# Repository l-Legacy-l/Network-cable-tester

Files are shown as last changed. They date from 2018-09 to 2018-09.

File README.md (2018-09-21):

# Network-cable-tester
This project was carried out in the first year of a bachelor's degree in computer science at the Haute école en Hainaut.

The purpose of the project is to check the operating status of a network cable (RJ45).
The cable tester includes the LED module and the PIC module. 
2 versions of the PCB have been made, the first one allows to be engraved only in single layer and the second one in double layer (space saving) .

In terms of PIC programming (PIC16F628A), 3 modes have been implemented: 
1. a short press of the button switches to the next LED
2. a long press speeds up the process by automatically switching to the following LED
3. a longer press lights up all the LEDs at the same time

# Usage

You can test the project with the Proteus simulation software and the right cabling.

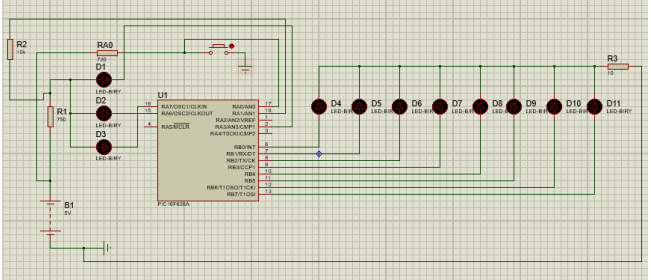
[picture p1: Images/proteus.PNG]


You can also try it in real with a breadboard, the right hardware and MPlab software to upload the code into the PIC.
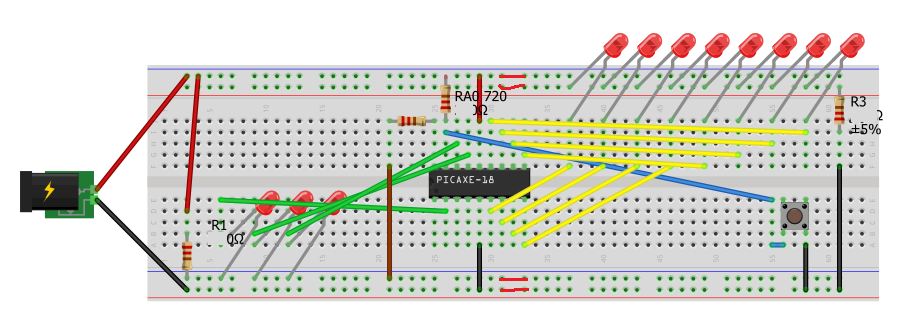
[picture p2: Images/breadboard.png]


You must use the compiled file NetworkCableTester.hex

For more information, you can consult the report detailing the software and hardware used and more detailed explanations (in French).

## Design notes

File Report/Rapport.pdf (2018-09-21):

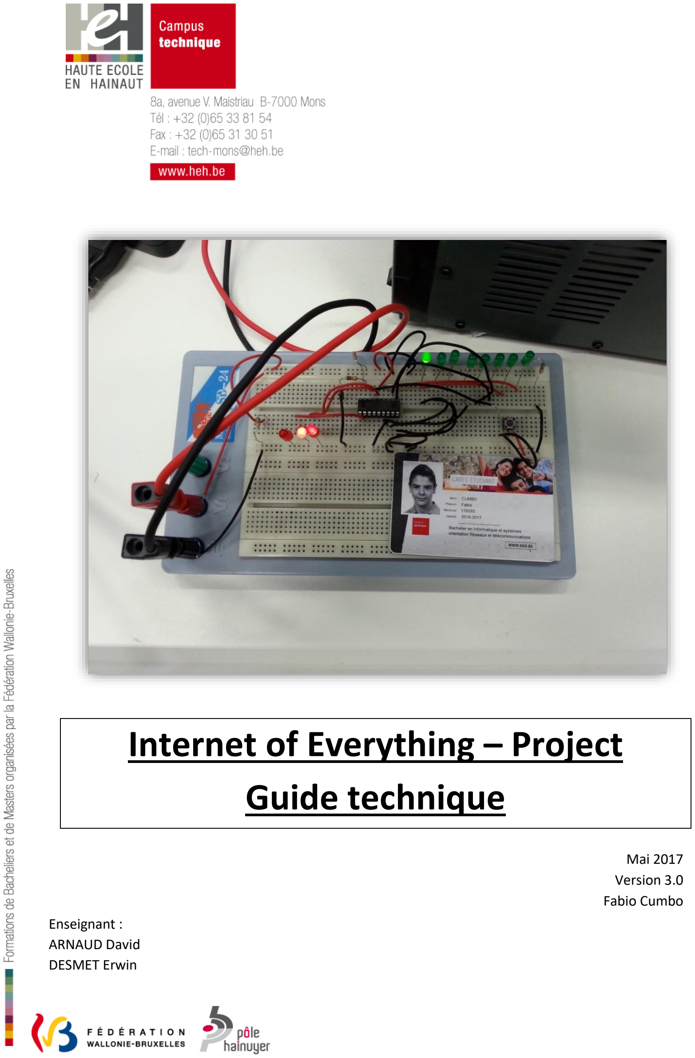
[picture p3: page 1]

# Internet of Everything – Project Guide technique

Mai 2017
Version 3.0
Fabio Cumbo
Enseignant :
ARNAUD David (https://ecampus.heh.be/user/view.php?id=1201&course=1)
DESMET Erwin (https://ecampus.heh.be/user/view.php?id=581&course=1)

Document confidentiel - Usage interne uniquement.

## 1. Informations générales sur le document

### Contact

Pour toute question ou remarque concernant ce document, merci de contacter :

Fabio Cumbo - Etudiant
Mail : fabio.cumbo@std.heh.be
HEH Campus Technique
8A Avenue Maistriau,
7000 Mons

### Confidentialité

Ce document contient des informations confidentielles et exclusives de la Haute École en Hainaut (HEH). Le service informatique ne peut divulguer les informations confidentielles contenues dans ce document à un tiers sans le consentement écrit de la HEH, hormis aux employés, enseignants ou directeurs qui ont besoin de connaître son contenu à des fins d'évaluation du document. Le service informatique se doit d'informer ces personnes de la nature confidentielle de ce document et d'obtenir leur accord pour préserver sa confidentialité.

### Informations sur le document

Nom du document | IoE project Technique.Docx
Version | Version 3.00
Niveau de confidentialité | Utilisation interne uniquement
Auteur du document | Fabio Cumbo

Contributeur(s)

Révisé par

Approuvé par

### Versions

Version | Date de parution | Modification réalisée par | Modification(s) apportée(s)
1.00 | 25/04/2017 | Fabio Cumbo | Création du document
2.00 | 29/05/2017 | Fabio Cumbo | Modification du code pour régler un problème lorsqu’on relâchait le bouton à la dernière LED dans le mode automatique.
3.00 | 30/05/2017 | Fabio Cumbo | Amélioration de l’optimisation du code.

### Documents connexes et/ou de référence

Nom du document | Description | Date
Q1 ETUDE DE PROJET 2016_Testeur_de_cables_reseauV1 | Document du cours d’étude de projet du premier quadrimestre | 16 sept 2016
Q2 EDPsuite 2016, Projet dinterfacage informatique.pdf | Document du cours de projet d’interfaçage informatique du deuxième quadrimestre | 6 fevrier 2017

### Table des matières

Document confidentiel

- Usage interne uniquement.

## 2. Introduction

L’objectif de cette fiche technique est de documenter la réalisation d’un testeur de câble réseau (RJ45) dans le cadre du cours d’étude de projet et du cours de projet d’interfaçage.
Les outils et explications nécessaire à la conception de ce projet seront donc élaboré dans ce document.

## 3. Logiciels et matériels nécessaire à la réalisation du projet

Matériels :
✓ | La liste des composants électronique (5.1.)
✓ | Une breadboard : Simulation réelle
✓ | Une pile 9V pour la breadboard
✓ | Le Pickit 3 pour injecter le code dans le PIC

Logiciels :
✓ | Eagle : Conception de la schématique et réalisation de la board
✓ | LARP : Conception d’ordinogrammes pour aider a réaliser l’algorithme
✓ | MikroC : IDE pour programmer le microcontrôleur PIC du testeur de câble
✓ | Proteus : Simulateur pour tester le programme
✓ | Fritzing : Simulation du câblage de la breadboard
✓ | MPlab : IPE pour injecter le code dans le PIC

## 4. Schéma générale sur Eagle

## 4.1. Module LED

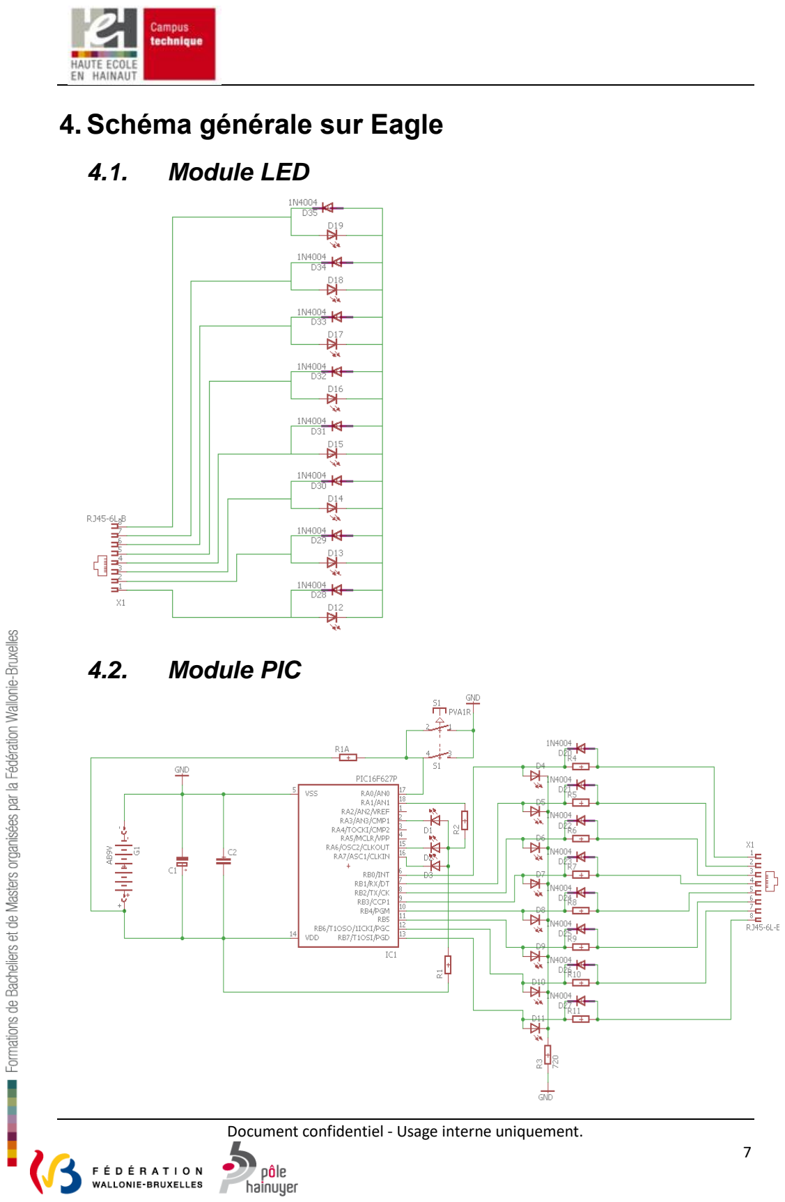
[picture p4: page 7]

## 4.2. Module PIC

## 4.3. Schéma sur Proteus

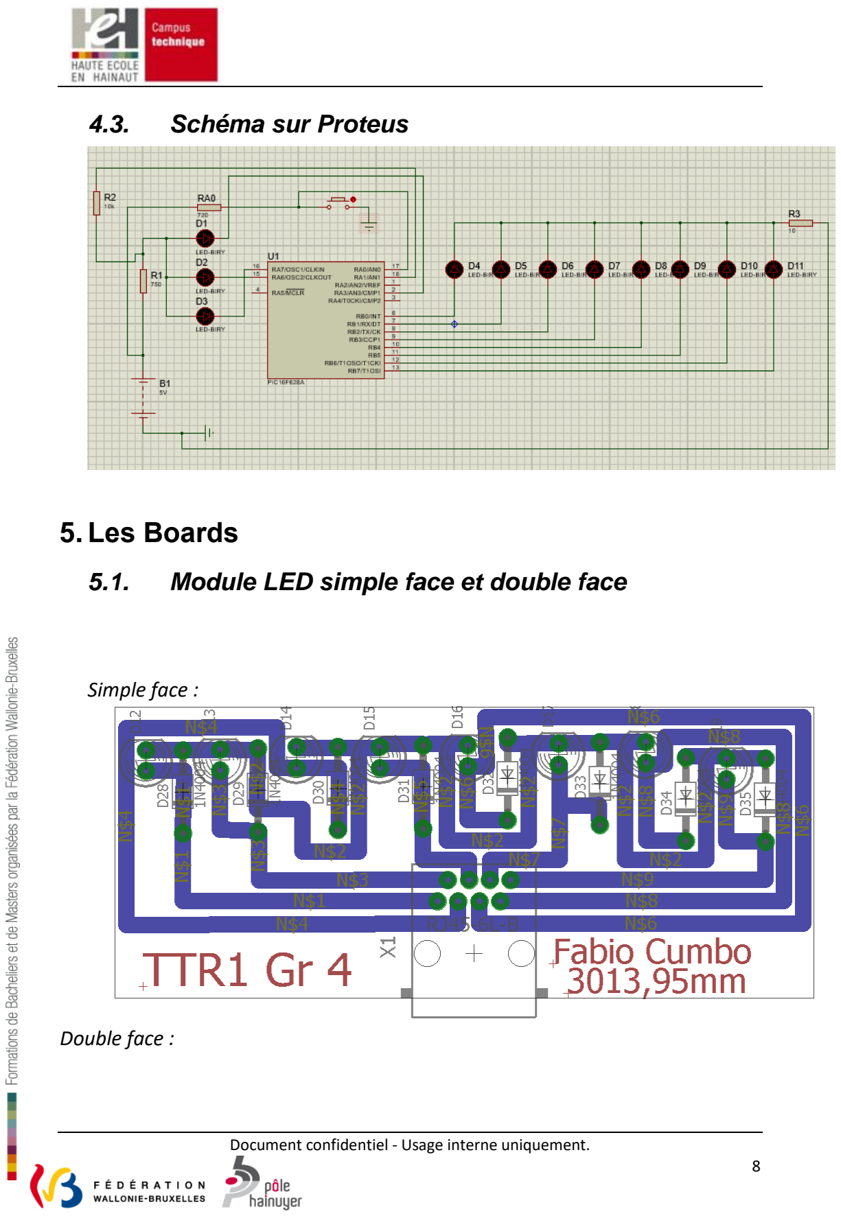
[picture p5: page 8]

## 5. Les Boards

## 5.1. Module LED simple face et double face

### Simple face :

### Double face :

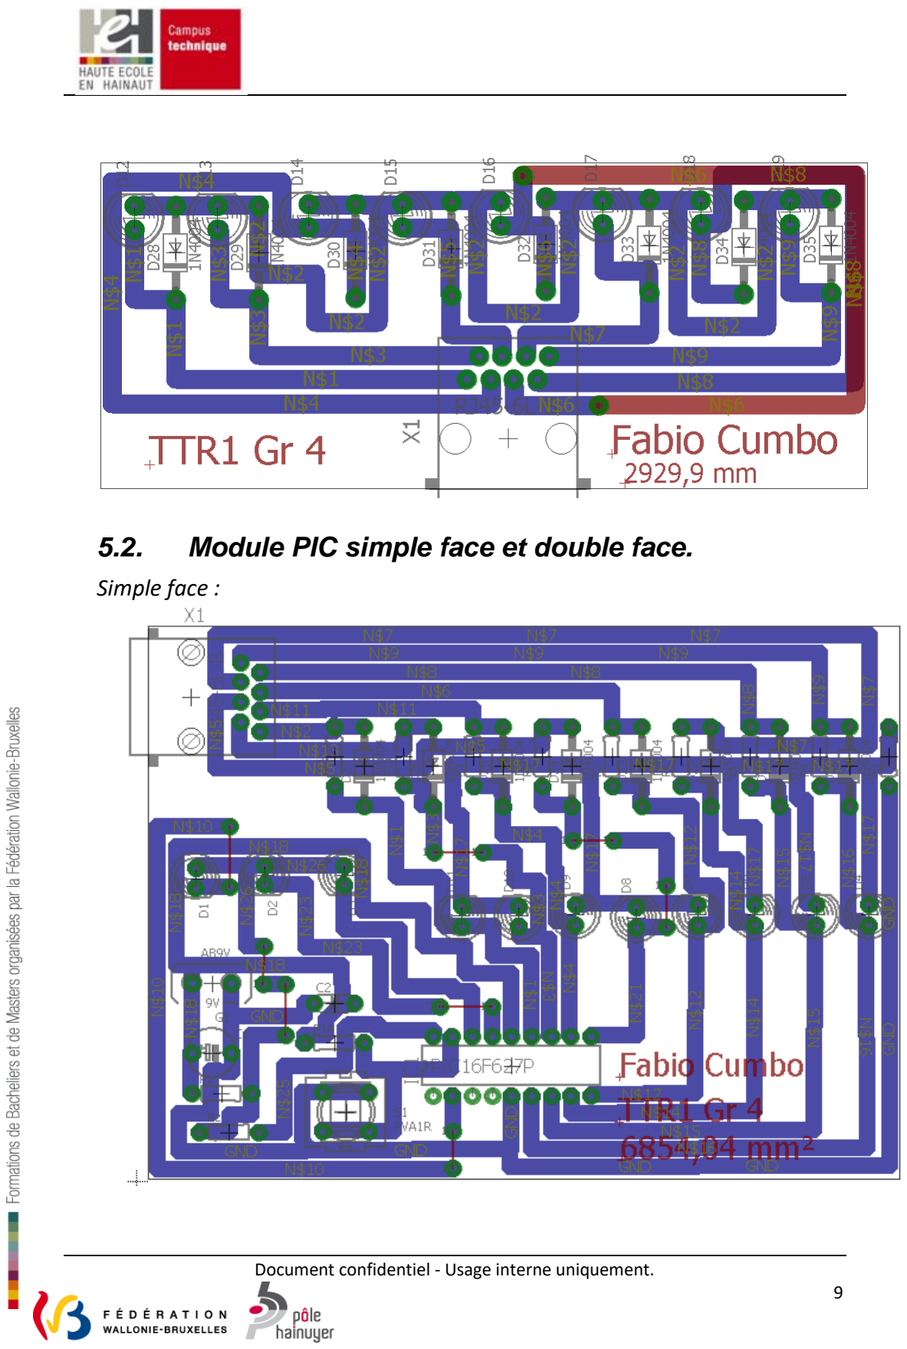
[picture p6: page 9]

5.2. Module PIC simple face et double face.

### Simple face :

### Double face :

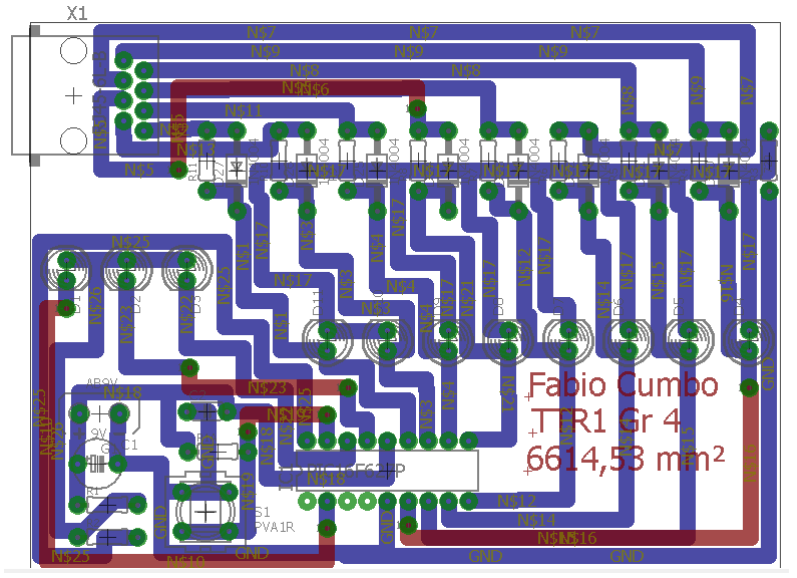
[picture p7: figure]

6. Les composants.

## 6.1. Liste des composants

Liste des composants | Quantité | Référence Eagle
Les LEDs 5 mm | 11 | LED5MM
Les diodes 1N4004 | 8 | 1N4004
Un connecteur RJ 45 | 1 | RJ45-6L-B
Un PIC 16F627A | 1 | PIC16F627P
Les résistances | 8x470, 1x680 et 1x10K | R-EU_0204/7
Un condensateur | 1x100uF/16V | CPOL-EUE5-6
Un condensateur polarisé | 1x100nF | C-EU050-024X044
Un Micro switch | 1 | PVA1R
Une pile | 1 | AB9V
Les LEDs 5 mm | 8 | LED5MM

Les diodes 1N4004 | 8 | 1N4004
Un connecteur RJ 45 | 1 | RJ45-6L-B

## 6.2. Comment obtenir des composants gratuitement

L’entreprise Microchip offre la possibilité de se procurer gratuitement jusqu’à 6 microcontrôleurs PIC par trimestre (2 x 3).
Il suffit de s’inscrire sur leur site internet : http://www.microchip.com/ et ensuite aller sur l’onglet « SAMPLE AND BUY et de choisir ces microcontrôleur ainsi que la quantité voulu.

## 7. Ordinogramme

## 7.1. LARP

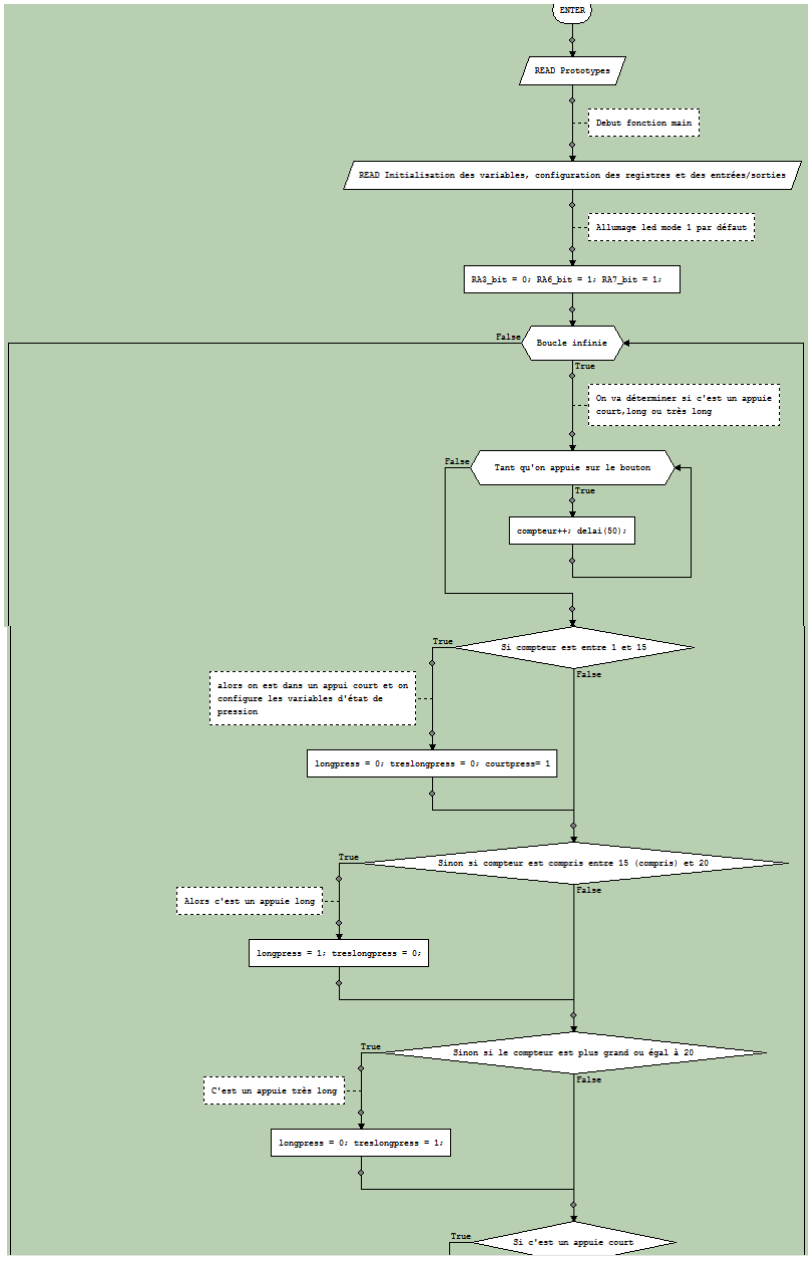
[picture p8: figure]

Document confidentiel

- Usage interne uniquement.

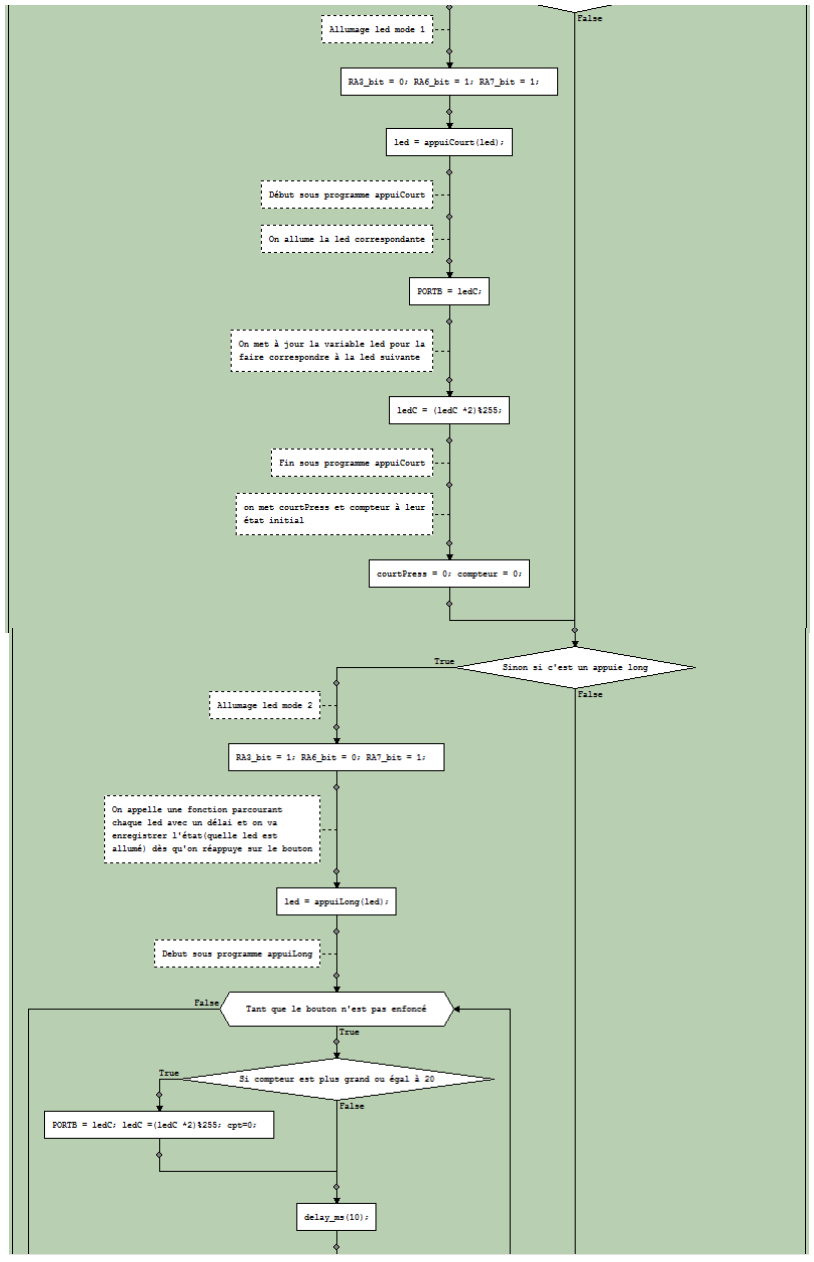
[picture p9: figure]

Document confidentiel

- Usage interne uniquement.

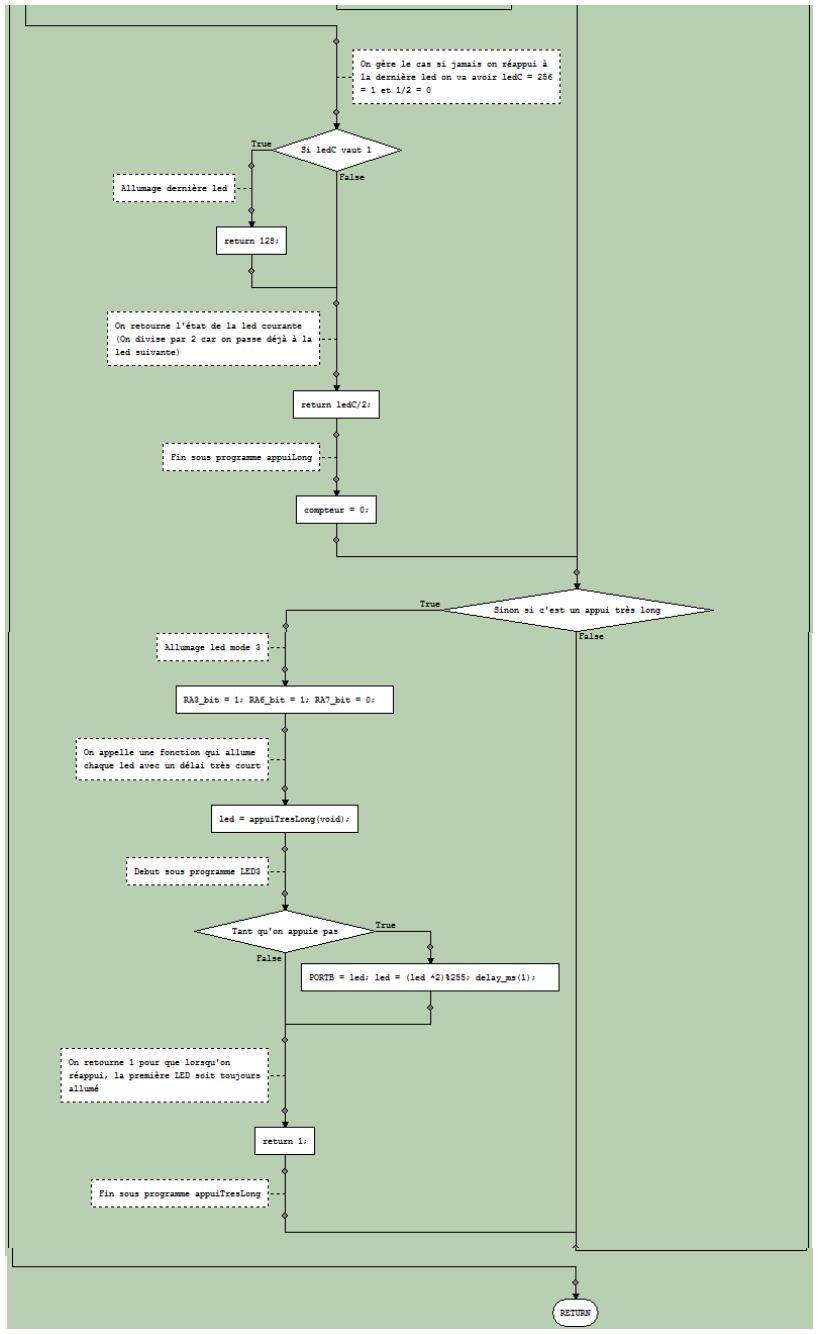
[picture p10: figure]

Document confidentiel

- Usage interne uniquement.

## 8. Programmation

## 8.1. Programmation du PIC

Pour développer le code du testeur de câble, nous avons utilisé le langage C ainsi que l’IDE MikroC développé par l’entreprise Mikroelektronika.
Il existe 2 possibilités pour pouvoir injecter le code dans le microcontrôleur PIC :
- Avec une Plaquette de développement EasyPic réalisé par Mikroelectronika
- Avec un programmateur PicKit et l’IPE MPlab

Nous avons utilisé la deuxième solution. Un fichier. HEX a été généré après compilation du code par MikroC et ce fichier a été introduit dans le PicKit pour pouvoir l’injecter dans le PIC.

Par ailleurs, nous avons utilisé le logiciel Proteus pour simuler le testeur de câble et s’assurer que le code est fonctionnel avant de passer à l’injection.

## 8.2. Premier

Commande | Description
while(RA0_bit==0) { compteur++ ; delay_ms(50); } | Cette partie va permettre d’incrémenter un compteur tous les 50 ms pour déterminer par la suite le type d’appui
if(compteur >= 1 && compteur < 15 { longPress = 0; tresLongPress = 0; courtPress = 1; } | On configure les paramètres pour un appui court
else if (compteur >= 15 && compteur <20) { longpress = 1; treslongpress = 0; } | On configure les paramètres pour un appui long
else if (compteur >= 20) { treslongpress = 1; longpress =0; } | On configure les paramètres pour un appui à 1 KhZ

char appuiCourt(char ledC) {
PORTB = ledC;
ledC = (ledC *2)%255;
}

Sous-programme permettant d’allumer la led correspondante en mode appui court. A chaque appui on va repasser par cette procédure qui va mettre à jour la led en faisant *2 pour "décaler" un bit vers la droite et ainsi passer à la led suivante et %255 pour retourner à la première si on est a 256

PORTB va donc prendre va donc prendre une de ses valeurs : 1-2-4-8-16-32-64-128

char appuiLong(char ledC)
{
int cpt =0;
for(cpt = 0; RA0_bit == 1; cpt++)
{
if(cpt>=20)
{
PORTB = ledC;
ledC = (ledC *2)%255;
cpt=0;
}
delay_ms(10);
}
if (ledC == 1)
{
return 128;
}
return ledC/2;
}

Sous-programme pour allumer chaque led en mode automatique (chenillard)

Tant qu’on appui pas, on incrémente un compteur pour déterminer le temps entre chaque led correspondante qui vont s’allumer avec un délai supplémentaire

Si on réappuie pour changer de mode, on renvoie la valeur de ledC/2 car on est déjà passé à la suivante et on veut s’arrêter à la led courante si on réappuie.

Cependant si ledC = 128 et qu’on passe à la suivante, on va avoir ledC = (128 * 2) %255 = 1 et si on reappuie sur le bouton pour changer de mode, on va avoir ledC = ½ = 0 et donc on aura aucune led d’allumer par la suite car (0 * 2) % 255 fera toujours 0. On doit donc gérer ce cas en renvoyant la dernière led si on réappuie à la dernière (donc 128)

char appuiTresLong()
{
char led = 1;
while(RA0_bit==1)
{
PORTB = led;
led = (led *2)%255;
delay_ms(1);
}
PORTB = 0
return 1;
}

Sous-programme permettant d’allumer toutes les leds en même temps

Tant qu’on n’appuie pas, on fait la procédure pour passer à la led suivante mais avec un délai très court (1ms)

Si on réappuie, on va toujours retomber sur la première led autrement, une led au hasard s’allumerait à chaque fois qu’on réappuie sur le bouton

9. Test sur plaquette d’essai ou sur board.

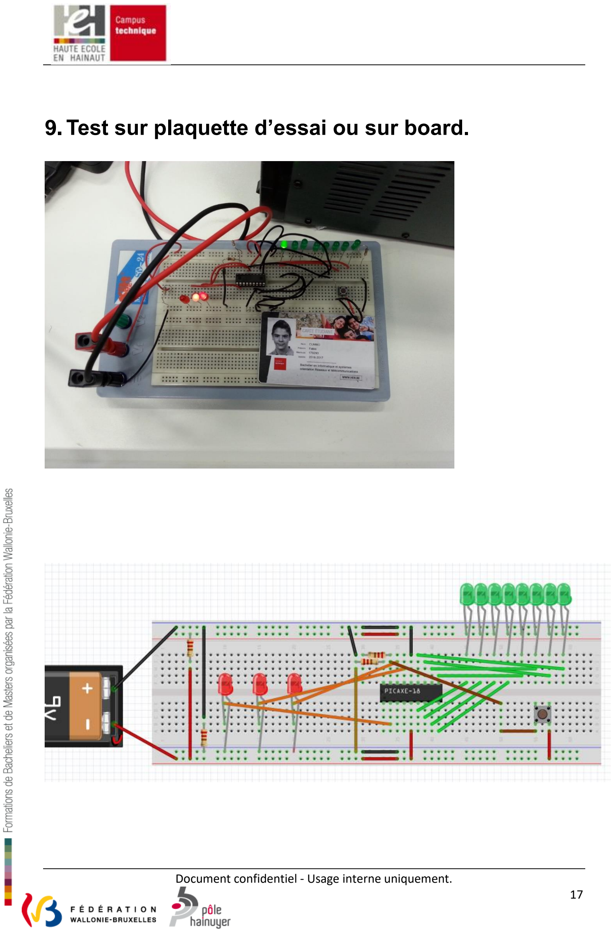
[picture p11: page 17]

## 10. Amélioration du code

Une amélioration du code permettant d’améliorer les fonctionnalités du testeur serait d’allumer la LED du mode correspondant avant de relâcher le bouton pour que la personne sache dans quel mode il se trouve avant de relâcher le bouton

Une autre amélioration aurait été de simplifier le moyen de détecter le type d’appui en utilisant seulement la variable compteur pour cela.

## 11. Synthèse et conclusion

11.1. Problème rencontré avec analyse des solutions.
- La disposition des composants du testeur pouvait être problématique. En effet pour permettre un routage plus facile, la disposition devait être logique et cohérente. Dans le cas contraire, il était parfois compliqué de réaliser les ponts.
- La difficulté à optimiser la taille du PCB m’a un peu posé problème. En effet, certains composants ont dû être déplacé pour diminuer la taille de la plaquette mais il fallait également penser à améliorer le routage de manière à éviter les pistes obliques pour permettre de gagner un maximum de place.
- Au niveau de la programmation du PIC, il a été difficile au départ de trouver le moyen de créer une boucle pour générer directement la séquence d’allumage et extinction automatique des LEDs sans devoir réécrire plusieurs fois la même chose. Il a fallu se rendre compte que l’on pouvait contrôler les LEDs facilement avec la variable PORTB et faire varier son état à chaque itération pour les 2 modes automatiques
11.2. Synthèse aboutissant sur une conclusion avec appréciation.

Nous avons abordé une thématique qui m’était pratiquement inconnu, j’ai donc appris de nouvelles choses qui je pense, peuvent m’être utile pour l’avenir. J’ai donc trouvé le cours intéressant pour ces raisons. Le projet s’est en général assez bien passé malgré une mauvaise appréhension au départ et les quelques problèmes rencontrés qui ont pu être résolu.

## Annexes

11.3. Toute la programmation.

// ******** Déclaration des prototypes ******** char appuiLong(char ledC);
char appuiCourt(char ledC);
char appuiTresLong();

void main()
{
// ******** Déclaration des variables ********
char longpress = 0; //Ici , on choisis des char pour ne pas allouer des espaces mémoires inutiles
char treslongpress = 0;
int compteur = 0;
char led = 1;
char courtpress = 0;

TRISA = 0b00000011 ; // port A en sortie sauf RA0 et RA1
PORTA = 0; | // mettre les sorties à zéro
TRISB = 0b00000000; | // Port B en sortie
PORTB = 0; | // mettre les sorties à zéro
pcon.OSCF = 1; | // configure le bit 3 du registre pcon pour 4 mhz
CMCON = 0b00000111;

RA3_bit = 0; // On allume la première led par défault pour savoir si c'est bien alimenté RA6_bit = 1;
RA7_bit = 1;
while(1)
{
while(RA0_bit==0) // Tant qu'on presse le bouton
{
compteur++; // On va incrémenter un compteur pour déterminer ensuite le type d'appui
delay_ms(50);
}

// ******** On va déterminer le type d'appui ********

if(compteur >= 1 && compteur < 15) //si compteur est entre 1 et 15 {
//On configure les paramètres pour un appui court

longpress = 0;
treslongpress = 0;
courtress = 1;
}
else if (compteur >= 15 && compteur <20)
{
//On configure les paramètres pour un appui long longpress = 1;
treslongpress = 0;
}
else if (compteur >= 20)
{
//On configure les paramètres pour un appui très long treslongpress = 1;
longpress =0;
}

// ******** On effectue les actions en fonction du type d'appui ********

if(courtPress == 1) //Si c'est un appuie court
{
RA3_bit = 0; //Allumage led mode 1 RA6_bit = 1;
RA7_bit = 1;

led = appuiCourt(led); //Appel fonction pour un appui court, la led va retenir la position et va devoir prendre une de ces valeurs: 1-2-4-8-16-32-64-128 courtPress = 0;
compteur = 0;
}
else if (longpress == 1) //Si on est dans un appuie long {
RA3_bit = 1; //Allumage led mode 2
RA6_bit = 0;
RA7_bit = 1;

led=appuiLong(led); //Appel fonction appui long compteur = 0;
}
else if (treslongpress == 1) // Appui très long
{
RA3_bit = 1; //Allumage led mode 3 RA6_bit = 1;

RA7_bit = 0;

led=appuiTresLong(void); //appel fonction mode 1khz compteur = 0;
}
}
}

// ******** Sous- programmes ********

char appuiCourt(char ledC) //Appui simple
{
PORTB = ledC; //On allume la led correspondante
ledC = (ledC *2)%255; //On met à jour cette led pour la faire correspondre à la led suivante //On fait donc *2 pour "décaler" un bit vers la droite et ainsi passer à la suivant // et %255 pour retourner à la première si on est a 256
}

char appuiLong(char ledC) //Appui long
{
int cpt =0;
for(cpt = 0; RA0_bit == 1; cpt++) //Tant qu'on appui pas
{
if(cpt>=20) // On incrémente un compteur pour déterminer le temps entre chaque led allumé
{
PORTB = ledC;
ledC = (ledC *2)%255;
cpt=0;
}
delay_ms(10);
}
if (ledC == 1) //On gère ce cas pour éviter d'avoir ledC = 256 = 1 et 1/2 = 0 {
return 128; //La dernière led s'allume
}
return ledC/2; //Si on relache on divise par 2 pour avoir la led courante car on a déjà passé à la suivante
}

char appuiTresLong() //Appui très long {
char led = 1;

while(RA0_bit==1) // Tant qu'on appui pas {
PORTB = led;
led = (led *2)%255;
delay_ms(1);
}
PORTB = 0; //si on réappuie, on allume d'office la première led return 1;
}

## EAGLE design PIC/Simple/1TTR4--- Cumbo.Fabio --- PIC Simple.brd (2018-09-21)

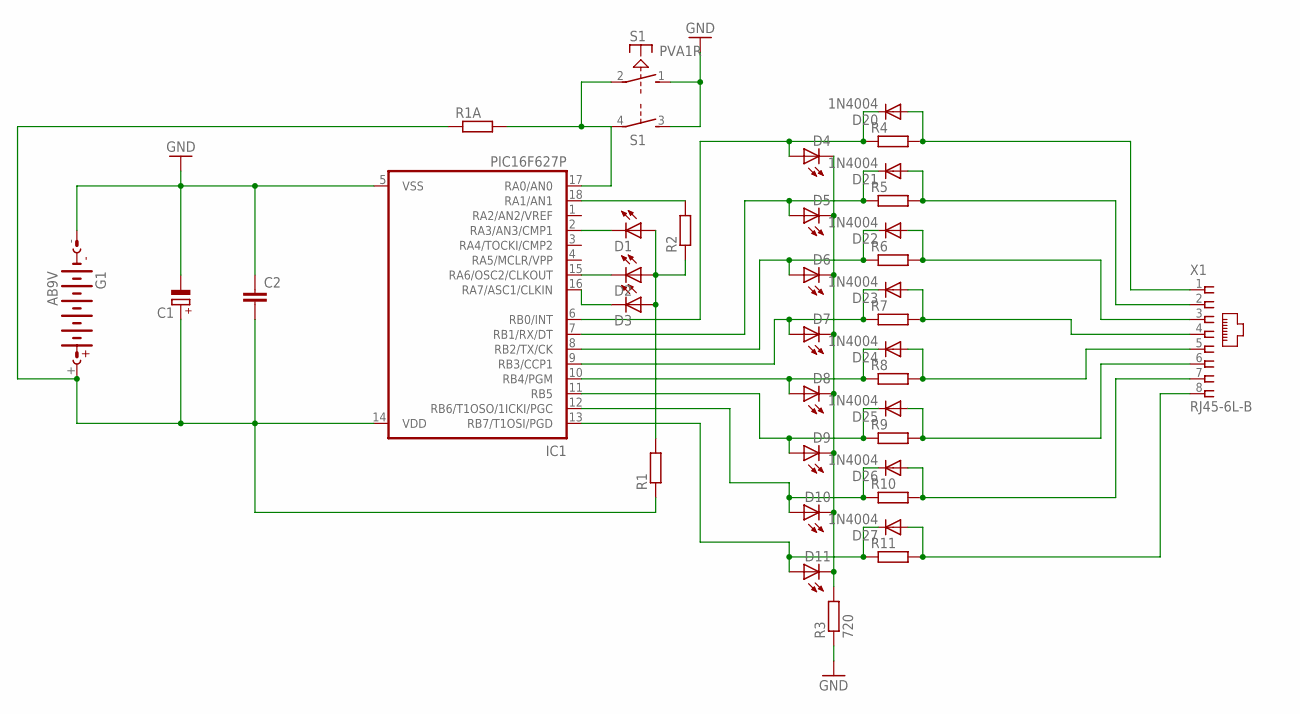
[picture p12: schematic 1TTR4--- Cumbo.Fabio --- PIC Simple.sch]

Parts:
C1: CPOL-EUE5-6; E5-6
C2: C-EU050-024X044; C050-024X044
D1, D2, D3, D4, D5, D6, D7, D8, D9, D10, D11: LED5MM
D20, D21, D22, D23, D24, D25, D26, D27: 1N4004; DO41-10
G1: AB9V
IC1: PIC16F627P; DIL18
R1, R1A, R2, R4, R5, R6, R7, R8, R9, R10, R11: R-EU_0204/7; 0204/7
R3: 720; 0204/7
S1: PVA1R
X1: RJ45-6L-B; RJ45-NO-SHIELD

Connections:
GND: C1.-, C2.1, G1.-, IC1.5 (VSS), R3.1, S1.1 (S), S1.3 (S)
unnamed: D11.A, D27.C, IC1.13 (RB7/T1OSI/PGD), R11.1
unnamed: D27.A, R11.2, X1.8
unnamed: D10.A, D26.C, IC1.12 (RB6/T1OSO/1ICKI/PGC), R10.1
unnamed: D9.A, D25.C, IC1.11 (RB5), R9.1
unnamed: D24.A, R8.2, X1.5
unnamed: D23.A, R7.2, X1.4
unnamed: D22.A, R6.2, X1.3
unnamed: D21.A, R5.2, X1.2
unnamed: D20.A, R4.2, X1.1
unnamed: D1.K (C), IC1.2 (RA3/AN3/CMP1)
unnamed: D25.A, R9.2, X1.6
unnamed: D7.A, D23.C, IC1.9 (RB3/CCP1), R7.1
unnamed: D26.A, R10.2, X1.7
unnamed: D6.A, D22.C, IC1.8 (RB2/TX/CK), R6.1
unnamed: D5.A, D21.C, IC1.7 (RB1/RX/DT), R5.1
unnamed: D4.A, D20.C, IC1.6 (RB0/INT), R4.1
unnamed: D4.K (C), D5.K (C), D6.K (C), D7.K (C), D8.K (C), D9.K (C), D10.K (C), D11.K (C), R3.2
unnamed: C1.+, C2.2, G1.+, IC1.14 (VDD), R1.1, R1A.1
unnamed: IC1.17 (RA0/AN0), R1A.2, S1.2, S1.4
unnamed: D8.A, D24.C, IC1.10 (RB4/PGM), R8.1
unnamed: D3.K (C), IC1.16 (RA7/ASC1/CLKIN)
unnamed: D2.K (C), IC1.15 (RA6/OSC2/CLKOUT)
unnamed: IC1.18 (RA1/AN1), R2.2
unnamed: D1.A, D2.A, D3.A, R1.2, R2.1

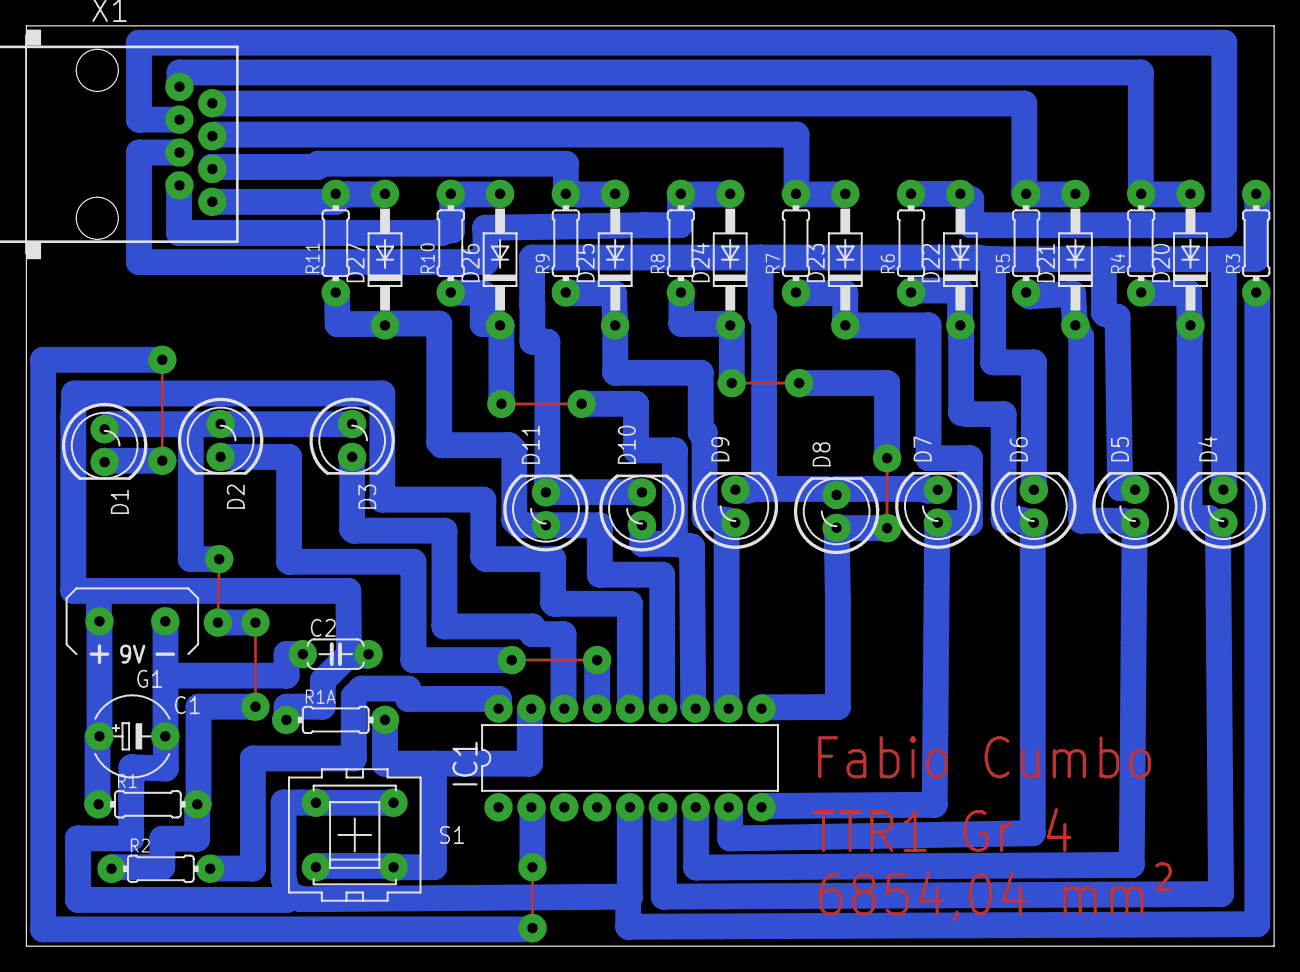
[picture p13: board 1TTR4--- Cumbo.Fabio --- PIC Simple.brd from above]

Board: 2 copper layers, 96.4 x 71.1 mm, 37 parts (0 on the bottom side), 25 nets.

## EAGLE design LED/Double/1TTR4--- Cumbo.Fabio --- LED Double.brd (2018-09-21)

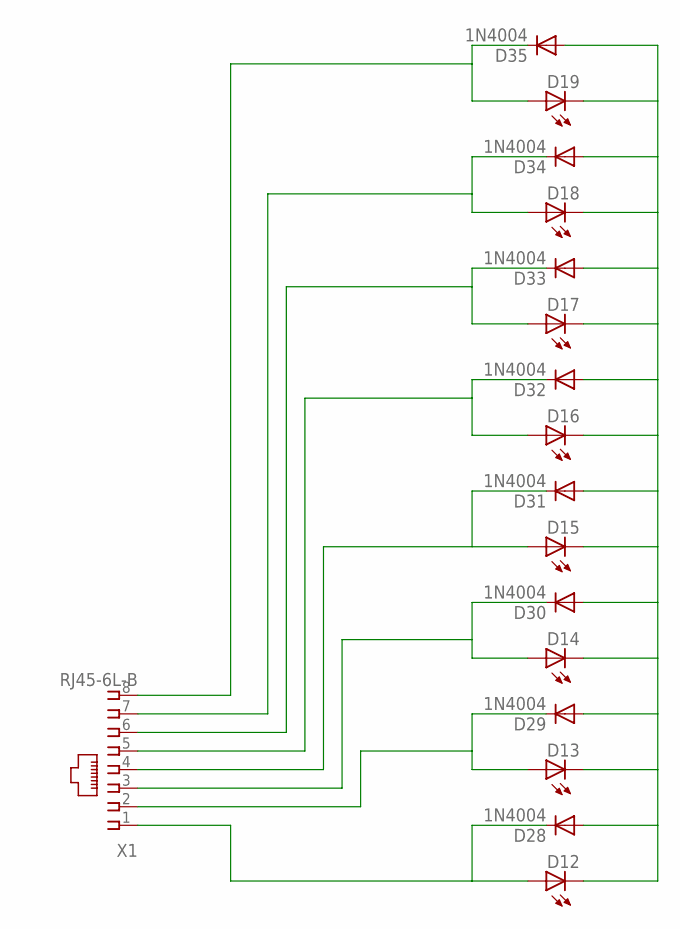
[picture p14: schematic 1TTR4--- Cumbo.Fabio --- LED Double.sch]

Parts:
D12, D13, D14, D15, D16, D17, D18, D19: LED5MM
D28, D29, D30, D31, D32, D33, D34, D35: 1N4004; DO41-10
X1: RJ45-6L-B; RJ45-NO-SHIELD

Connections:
unnamed: D12.A, D28.C, X1.1
unnamed: D12.K (C), D13.K (C), D14.K (C), D15.K (C), D16.K (C), D17.K (C), D18.K (C), D19.K (C), D28.A, D29.A, D30.A, D31.A, D32.A, D33.A, D34.A, D35.A
unnamed: D13.A, D29.C, X1.2
unnamed: D14.A, D30.C, X1.3
unnamed: D15.A, D31.C, X1.4
unnamed: D16.A, D32.C, X1.5
unnamed: D17.A, D33.C, X1.6
unnamed: D18.A, D34.C, X1.7
unnamed: D19.A, D35.C, X1.8

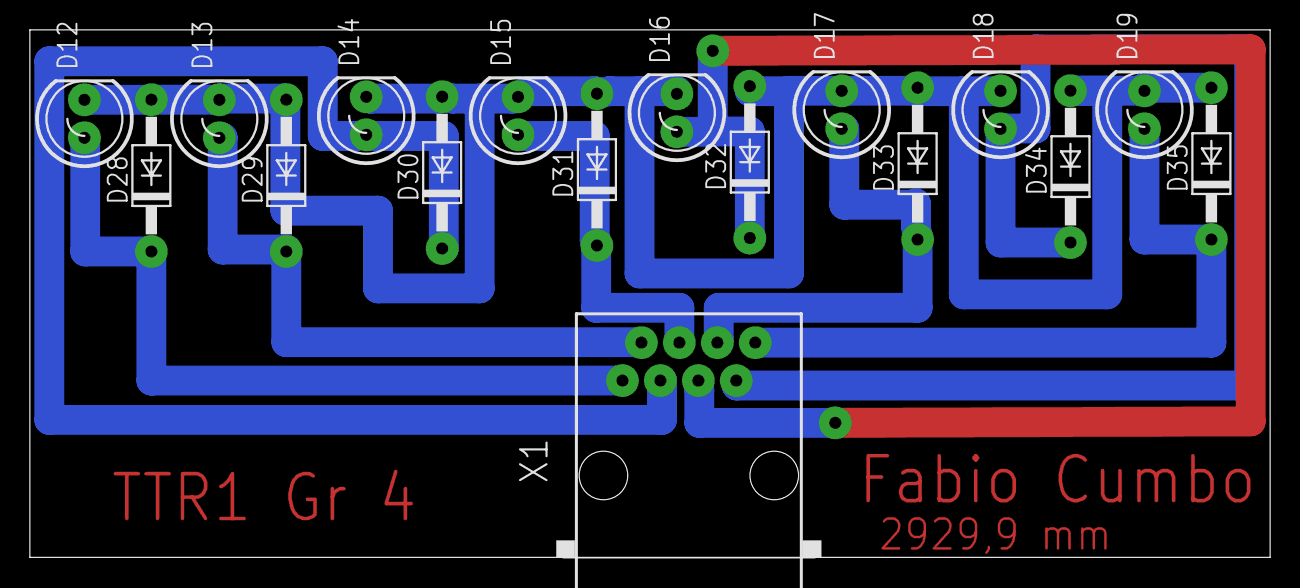
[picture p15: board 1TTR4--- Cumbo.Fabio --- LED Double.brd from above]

Board: 2 copper layers, 83.0 x 35.3 mm, 17 parts (0 on the bottom side), 9 nets.
